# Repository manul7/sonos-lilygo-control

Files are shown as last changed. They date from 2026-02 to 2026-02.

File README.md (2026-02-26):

# TTGO Sonos Volume Controller

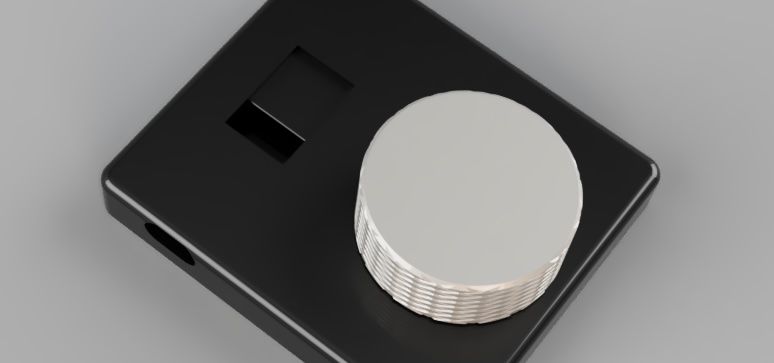
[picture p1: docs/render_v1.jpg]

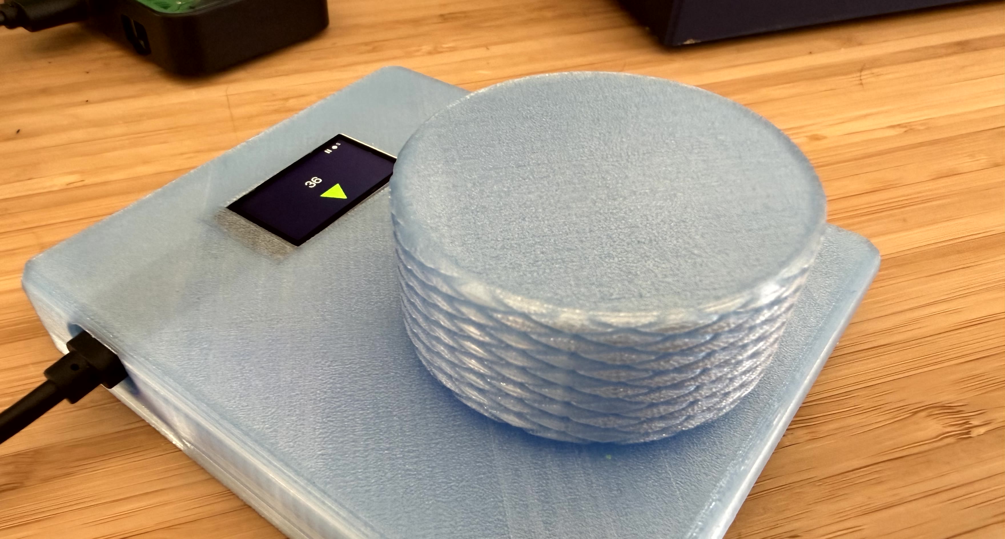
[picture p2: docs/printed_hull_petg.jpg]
Hull


ESP32-based hardware volume knob for Sonos speakers using a TTGO T-Display board.

## Features

- Volume displayed as a fill-proportional triangle with numeric readout
- Status icons (WiFi, Sonos connectivity, play/pause state) in top-right corner
- Rotary encoder for smooth volume adjustment with batching
- Encoder button toggles play/pause
- Built-in buttons as fallback (up/down with auto-repeat)
- WiFi connectivity to Sonos via UPnP/SOAP
- Auto-reconnect on WiFi drop

## Hardware

- **Board**: TTGO T-Display (ESP32 with 1.14" TFT, 240x135)
- **Rotary encoder**: CLK → GPIO25, DT → GPIO26, SW → GPIO27
- **Built-in buttons**: GPIO35 (A), GPIO0 (B)

## Project Structure

```
ttgo_counter/
├── ttgo_counter.ino   # Main sketch (UI, buttons, WiFi)
├── config.h           # Configuration (excluded from git)
├── config.h.example   # Configuration template
├── sonos.h            # Sonos API declarations
├── sonos.cpp          # Sonos UPnP/SOAP implementation
├── bom.md             # Bill of materials
├── hull/              # 3D-printable enclosure (STL files)
│   ├── TopHull_v1.stl
│   ├── BottomHull_v0.stl
│   └── knob_v0.stl
└── README.md
```

## Dependencies

Install via Arduino Library Manager:

| Library | Purpose |
|---|---|
| TFT_eSPI | Display driver |
| WiFi | ESP32 WiFi (built-in) |
| HTTPClient | HTTP requests (built-in) |

### TFT_eSPI Configuration

In `User_Setup_Select.h`, enable:
```cpp
#include <User_Setups/Setup25_TTGO_T_Display.h>
```

## Configuration

Copy `config.h.example` to `config.h` and edit:

```cpp
// WiFi
static const char* WIFI_SSID = "YourNetwork";
static const char* WIFI_PASSWORD = "YourPassword";

// Sonos
static const char* SONOS_IP = "192.168.x.x";  // Your Sonos speaker IP
static const int SONOS_PORT = 1400;
static const int VOLUME_STEP = 1;

// Hardware
static const int BUTTON_A_PIN = 35;
static const int BUTTON_B_PIN = 0;
static const int ENCODER_CLK_PIN = 25;
static const int ENCODER_DT_PIN = 26;
static const int ENCODER_SW_PIN = 27;

// Display
static const uint8_t DISPLAY_ROTATION = 1;
static const bool DISPLAY_INVERT = true;

// UI Colors (RGB565)
static const uint16_t COLOR_TRI_FILL  = 0x07E0;  // bright green
static const uint16_t COLOR_ICON_ON   = 0xFFFF;  // white
static const uint16_t COLOR_ICON_OFF  = 0x4208;  // dark gray

// Triangle geometry
static const int TRI_HEIGHT   = 100;
static const int TRI_BASE     = 116;
static const int TRI_OFFSET_Y = 5;

// Status icon layout (top-right)
static const int ICON_SIZE   = 10;
static const int ICON_GAP    = 4;
static const int ICON_MARGIN = 6;

// Timing
static const uint32_t DEBOUNCE_MS = 35;
static const uint32_t LONG_PRESS_MS = 700;
static const uint32_t REPEAT_INTERVAL_MS = 300;
```

Note: `config.h` contains credentials and is excluded from version control.

## Usage

- **Encoder rotation**: Volume up/down
- **Encoder button**: Play/pause toggle
- **Button A (GPIO35)**: Volume up (fallback)
- **Button B (GPIO0)**: Volume down (fallback)
- Hold built-in buttons for auto-repeat

Single-button mode activates automatically if only one built-in button is detected.

## Display

The screen shows a triangle that fills proportionally to the current volume (0-100), with the numeric value overlaid. Status icons in the top-right corner indicate:

- **WiFi**: filled circle (green = connected, gray = disconnected)
- **Sonos**: "S" letter (green = reachable, gray = unreachable)
- **Playback**: play/pause icon reflecting current transport state

## Enclosure

3D-printable STL files are in [hull/](hull/). Print the top and bottom hull halves plus the encoder knob. See [bom.md](bom.md) for parts sourcing.

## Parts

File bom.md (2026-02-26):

# Bill of Materials

- **LilyGO TTGO T-Display** - ESP32 board with 1.14" TFT display
  [LilyGO Official Store](https://lilygo.cc/en-us/products/t-display)

- **Rotary Encoder (5-Pack)** - Taiss KY-040 rotary encoder module for Arduino, ESP32, ESP8266, Raspberry Pi
  [Amazon](https://www.amazon.com/dp/B07F26CT6B)

- **PETG** - Plastic for the hull print
- **Nylon hex M3 stud** x 4
- **Nylon M3 screw** x 4

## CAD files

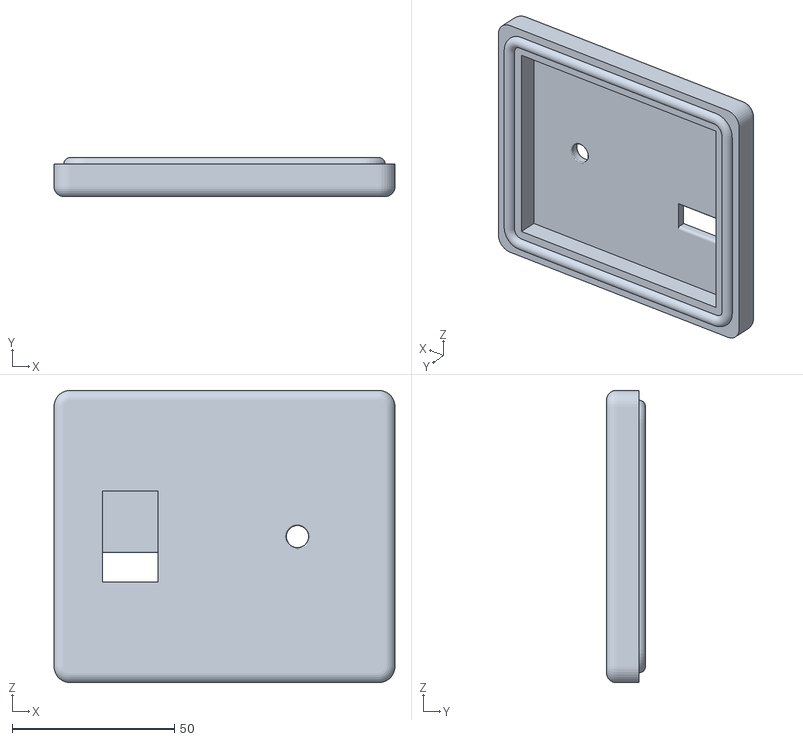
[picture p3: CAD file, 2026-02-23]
hull/TopHull_v1.stl
105.0 x 12.0 x 90.0

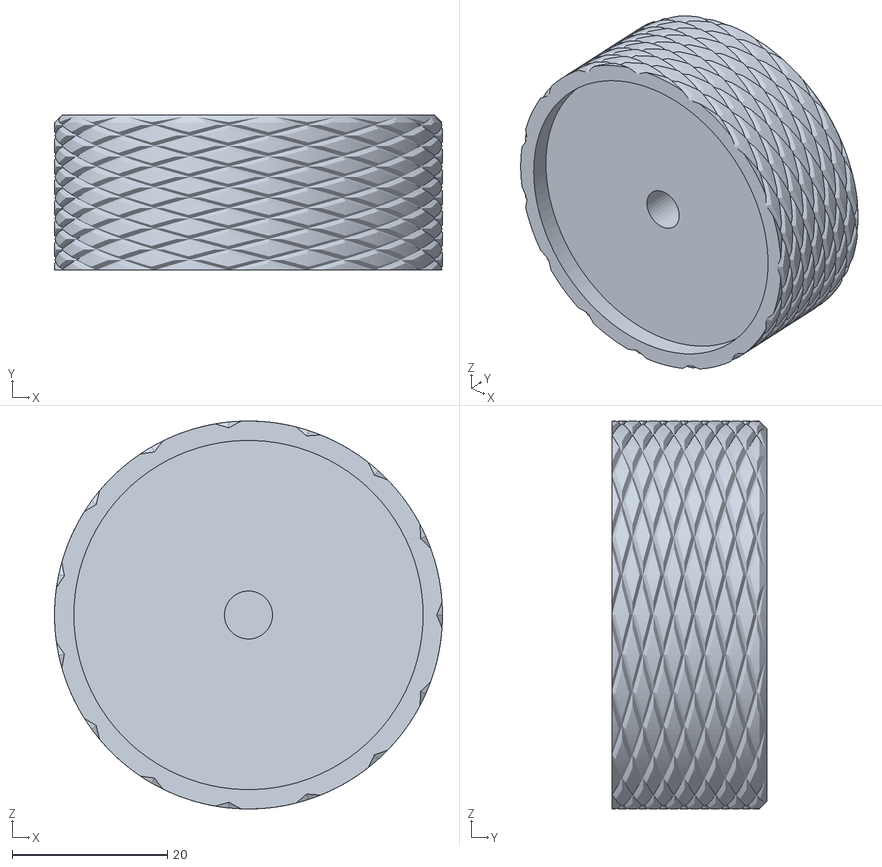
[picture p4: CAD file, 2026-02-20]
hull/knob_v0.stl
50.0 x 20.0 x 50.0

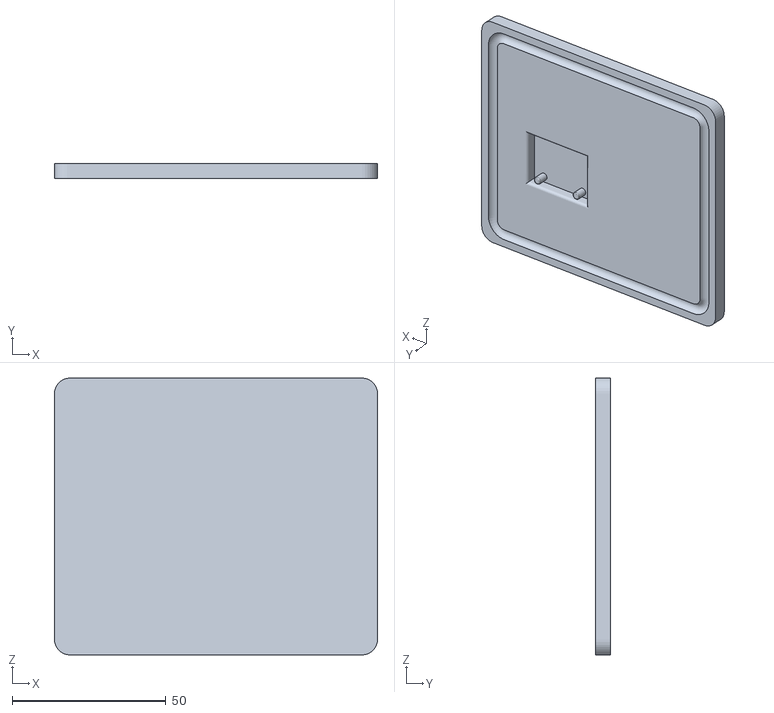
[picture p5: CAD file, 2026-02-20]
hull/BottomHull_v0.stl
105.0 x 5.00 x 90.0

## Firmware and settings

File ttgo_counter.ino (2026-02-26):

#include <TFT_eSPI.h>
#include <WiFi.h>
#include "config.h"
#include "sonos.h"

namespace {

struct Button {
  int pin;
  bool active_low;
  bool enabled;
  bool raw_pressed;
  bool stable_pressed;
  uint32_t last_raw_change_ms;
  uint32_t pressed_since_ms;
};

enum class ButtonEventType { None, Press, Release };

struct ButtonEvent {
  ButtonEventType type;
  uint32_t held_ms;
};

TFT_eSPI tft = TFT_eSPI();
Button button_a{};
Button button_b{};
Button encoder_sw{};

int current_volume = 0;
bool single_button_mode = false;
uint32_t last_repeat_a_ms = 0;
uint32_t last_repeat_b_ms = 0;

// Encoder state
volatile int encoder_pos = 0;
int last_encoder_pos = 0;
volatile int last_clk_state = HIGH;

// Volume batching
uint32_t last_encoder_change_ms = 0;
int pending_volume_delta = 0;
static const uint32_t VOLUME_BATCH_MS = 50;  // batch rapid turns

int majorityRead(int pin) {
  int highs = 0;
  for (int i = 0; i < 7; ++i) {
    highs += (digitalRead(pin) == HIGH) ? 1 : 0;
    delayMicroseconds(250);
  }
  return (highs >= 4) ? HIGH : LOW;
}

bool readPressed(const Button &button) {
  const int level = majorityRead(button.pin);
  return button.active_low ? (level == LOW) : (level == HIGH);
}

bool pinLooksStable(int pin) {
  int transitions = 0;
  int prev = majorityRead(pin);
  for (int i = 0; i < 120; ++i) {
    delay(2);
    const int now = majorityRead(pin);
    if (now != prev) {
      ++transitions;
      prev = now;
    }
  }
  return transitions <= 4;
}

Button makeButton(int pin, bool active_low) {
  Button b{};
  b.pin = pin;
  b.active_low = active_low;
  b.enabled = pinLooksStable(pin);
  b.raw_pressed = b.enabled ? readPressed(b) : false;
  b.stable_pressed = b.raw_pressed;
  b.last_raw_change_ms = millis();
  b.pressed_since_ms = 0;
  return b;
}

ButtonEvent updateButton(Button &b, uint32_t now_ms) {
  if (!b.enabled) {
    return {ButtonEventType::None, 0};
  }

  const bool raw_pressed = readPressed(b);
  if (raw_pressed != b.raw_pressed) {
    b.raw_pressed = raw_pressed;
    b.last_raw_change_ms = now_ms;
  }

  if ((now_ms - b.last_raw_change_ms) < DEBOUNCE_MS) {
    return {ButtonEventType::None, 0};
  }

  if (b.stable_pressed == b.raw_pressed) {
    return {ButtonEventType::None, 0};
  }

  b.stable_pressed = b.raw_pressed;
  if (b.stable_pressed) {
    b.pressed_since_ms = now_ms;
    return {ButtonEventType::Press, 0};
  }

  const uint32_t held = now_ms - b.pressed_since_ms;
  return {ButtonEventType::Release, held};
}

int pickFontToFit(const char *text, int max_width, int start_font, int min_font) {
  for (int font = start_font; font >= min_font; --font) {
    if (tft.textWidth(text, font) <= max_width) {
      return font;
    }
  }
  return min_font;
}

void drawScreen() {
  tft.fillScreen(TFT_BLACK);

  const int w = tft.width();   // 240
  const int h = tft.height();  // 135

  // Inverted triangle — flat edge at top, apex at bottom
  const int cx = w / 2;
  const int tri_cy = h / 2 + TRI_OFFSET_Y;
  const int top_y = tri_cy - TRI_HEIGHT / 2;
  const int bot_y = tri_cy + TRI_HEIGHT / 2;
  const int half_base = TRI_BASE / 2;

  // Fill from apex (bottom) upward proportional to volume.
  // The filled region is a smaller triangle sharing the apex.
  if (current_volume > 0) {
    const float frac = current_volume / 100.0f;
    // fill_y = line where fill stops (moves up from bot_y toward top_y)
    const int fill_y = bot_y - (int)(frac * TRI_HEIGHT);
    // Width at fill_y: triangle widens toward the top
    const int fill_half_w = (int)(half_base * frac);

    tft.fillTriangle(cx, bot_y,
                     cx - fill_half_w, fill_y,
                     cx + fill_half_w, fill_y,
                     COLOR_TRI_FILL);
  }

  // Volume number centered in upper portion of triangle
  char vol_text[8];
  snprintf(vol_text, sizeof(vol_text), "%d", current_volume);
  tft.setTextDatum(MC_DATUM);
  tft.setTextColor(TFT_WHITE);
  const int text_y = top_y + TRI_HEIGHT / 3;
  const int font = pickFontToFit(vol_text, half_base, 4, 2);
  tft.drawString(vol_text, cx, text_y, font);

  // Status icons — top-right corner
  const bool wifi_ok = (WiFi.status() == WL_CONNECTED);
  const bool sonos_ok = sonosIsConnected();
  const bool playing = sonosIsPlaying();

  // Rightmost icon x position
  int ix = w - ICON_MARGIN - ICON_SIZE;
  const int iy = ICON_MARGIN;

  // Sonos indicator: "S" letter
  tft.setTextDatum(TL_DATUM);
  tft.setTextColor(sonos_ok ? COLOR_ICON_ON : COLOR_ICON_OFF);
  tft.drawString("S", ix, iy, 1);

  ix -= (ICON_SIZE + ICON_GAP);

  // WiFi indicator: filled circle
  tft.fillCircle(ix + ICON_SIZE / 2, iy + ICON_SIZE / 2, ICON_SIZE / 2 - 1,
                 wifi_ok ? COLOR_ICON_ON : COLOR_ICON_OFF);

  ix -= (ICON_SIZE + ICON_GAP);

  // Play/pause indicator
  if (playing) {
    // Triangle (play icon)
    tft.fillTriangle(ix, iy, ix, iy + ICON_SIZE,
                     ix + ICON_SIZE, iy + ICON_SIZE / 2,
                     COLOR_ICON_ON);
  } else {
    // Two bars (pause icon)
    const int bar_w = 3;
    const int gap = 2;
    tft.fillRect(ix, iy, bar_w, ICON_SIZE, COLOR_ICON_ON);
    tft.fillRect(ix + bar_w + gap, iy, bar_w, ICON_SIZE, COLOR_ICON_ON);
  }
}

void changeVolume(int delta) {
  int new_volume = current_volume + delta;
  if (new_volume < 0) new_volume = 0;
  if (new_volume > 100) new_volume = 100;
  if (new_volume == current_volume) return;

  if (sonosSetVolume(new_volume)) {
    current_volume = new_volume;
    drawScreen();
  }
}

void showStatus(const char* msg) {
  tft.fillScreen(TFT_BLACK);
  tft.setTextColor(TFT_WHITE, TFT_BLACK);
  tft.setTextDatum(MC_DATUM);
  tft.drawString(msg, tft.width() / 2, tft.height() / 2, 4);
}

bool checkWiFi() {
  if (WiFi.status() == WL_CONNECTED) return true;

  showStatus("WiFi...");
  WiFi.reconnect();

  uint32_t start = millis();
  while (WiFi.status() != WL_CONNECTED && (millis() - start) < 10000) {
    delay(250);
  }

  if (WiFi.status() == WL_CONNECTED) {
    drawScreen();
    return true;
  }
  return false;
}

void IRAM_ATTR encoderISR() {
  const int clk = digitalRead(ENCODER_CLK_PIN);
  const int dt = digitalRead(ENCODER_DT_PIN);
  if (clk != last_clk_state && clk == LOW) {
    encoder_pos += (dt != clk) ? 1 : -1;
  }
  last_clk_state = clk;
}

}  // namespace

void setup() {
  Serial.begin(115200);
  delay(120);

  pinMode(TFT_BL, OUTPUT);
  digitalWrite(TFT_BL, HIGH);

  // GPIO35 is input-only; GPIO0 usually has external pull-up.
  pinMode(BUTTON_A_PIN, INPUT);
  pinMode(BUTTON_B_PIN, INPUT_PULLUP);

  // Rotary encoder
  pinMode(ENCODER_CLK_PIN, INPUT_PULLUP);
  pinMode(ENCODER_DT_PIN, INPUT_PULLUP);
  pinMode(ENCODER_SW_PIN, INPUT_PULLUP);
  last_clk_state = digitalRead(ENCODER_CLK_PIN);
  attachInterrupt(digitalPinToInterrupt(ENCODER_CLK_PIN), encoderISR, CHANGE);
  delay(20);

  button_a = makeButton(BUTTON_A_PIN, true);
  button_b = makeButton(BUTTON_B_PIN, true);
  encoder_sw = makeButton(ENCODER_SW_PIN, true);

  // Some board variants expose only one usable GPIO button.
  single_button_mode = (button_a.enabled && !button_b.enabled);

  Serial.printf("button_a_enabled=%d button_b_enabled=%d single_mode=%d\n",
                button_a.enabled ? 1 : 0,
                button_b.enabled ? 1 : 0,
                single_button_mode ? 1 : 0);

  tft.init();
  tft.setRotation(DISPLAY_ROTATION);
  tft.invertDisplay(DISPLAY_INVERT);

  // Show connecting message
  tft.fillScreen(TFT_BLACK);
  tft.setTextColor(TFT_WHITE, TFT_BLACK);
  tft.setTextDatum(MC_DATUM);
  tft.drawString("WiFi...", tft.width() / 2, tft.height() / 2, 4);

  // Connect to WiFi
  WiFi.begin(WIFI_SSID, WIFI_PASSWORD);
  while (WiFi.status() != WL_CONNECTED) {
    delay(500);
    Serial.print(".");
  }
  Serial.printf("\nConnected! IP: %s\n", WiFi.localIP().toString().c_str());

  // Get initial volume from Sonos
  tft.drawString("Sonos...", tft.width() / 2, tft.height() / 2, 4);
  current_volume = sonosGetVolume();
  if (current_volume < 0) current_volume = 0;

  drawScreen();
}

void loop() {
  const uint32_t now = millis();

  // Handle rotary encoder rotation with batching
  noInterrupts();
  const int pos = encoder_pos;
  interrupts();

  if (pos != last_encoder_pos) {
    pending_volume_delta += (pos - last_encoder_pos) * VOLUME_STEP;
    last_encoder_pos = pos;
    last_encoder_change_ms = now;
  }

  // Apply batched volume change after settling
  if (pending_volume_delta != 0 && (now - last_encoder_change_ms) >= VOLUME_BATCH_MS) {
    if (checkWiFi()) {
      changeVolume(pending_volume_delta);
    }
    pending_volume_delta = 0;
  }

  // Handle encoder SW button for play/pause
  const ButtonEvent sw_event = updateButton(encoder_sw, now);
  if (sw_event.type == ButtonEventType::Press) {
    if (checkWiFi()) {
      sonosTogglePlayPause();
      drawScreen();
    }
  }

  // Keep built-in buttons as fallback
  const ButtonEvent a_event = updateButton(button_a, now);
  const ButtonEvent b_event = updateButton(button_b, now);

  if (single_button_mode) {
    if (a_event.type == ButtonEventType::Release) {
      changeVolume((a_event.held_ms >= LONG_PRESS_MS) ? -VOLUME_STEP : +VOLUME_STEP);
    }
  } else {
    if (a_event.type == ButtonEventType::Press) {
      changeVolume(+VOLUME_STEP);
      last_repeat_a_ms = now;
    }
    if (b_event.type == ButtonEventType::Press) {
      changeVolume(-VOLUME_STEP);
      last_repeat_b_ms = now;
    }
    if (button_a.stable_pressed && (now - last_repeat_a_ms) >= REPEAT_INTERVAL_MS) {
      changeVolume(+VOLUME_STEP);
      last_repeat_a_ms = now;
    }
    if (button_b.stable_pressed && (now - last_repeat_b_ms) >= REPEAT_INTERVAL_MS) {
      changeVolume(-VOLUME_STEP);
      last_repeat_b_ms = now;
    }
  }

  delay(4);
}

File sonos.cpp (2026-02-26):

#include "sonos.h"

namespace {

bool s_connected = false;
bool s_playing = false;

String sonosRenderingUrl() {
  return String("http://") + SONOS_IP + ":" + SONOS_PORT + "/MediaRenderer/RenderingControl/Control";
}

String sonosTransportUrl() {
  return String("http://") + SONOS_IP + ":" + SONOS_PORT + "/MediaRenderer/AVTransport/Control";
}

}  // namespace

static const int HTTP_TIMEOUT_MS = 2000;

bool sonosIsConnected() { return s_connected; }
bool sonosIsPlaying()   { return s_playing; }

int sonosGetVolume() {
  HTTPClient http;
  http.begin(sonosRenderingUrl());
  http.setTimeout(HTTP_TIMEOUT_MS);
  http.addHeader("Content-Type", "text/xml; charset=\"utf-8\"");
  http.addHeader("SOAPACTION", "\"urn:schemas-upnp-org:service:RenderingControl:1#GetVolume\"");

  const char* body =
    "<?xml version=\"1.0\"?>"
    "<s:Envelope xmlns:s=\"http://schemas.xmlsoap.org/soap/envelope/\" "
    "s:encodingStyle=\"http://schemas.xmlsoap.org/soap/encoding/\">"
    "<s:Body>"
    "<u:GetVolume xmlns:u=\"urn:schemas-upnp-org:service:RenderingControl:1\">"
    "<InstanceID>0</InstanceID>"
    "<Channel>Master</Channel>"
    "</u:GetVolume>"
    "</s:Body>"
    "</s:Envelope>";

  int httpCode = http.POST(body);
  int volume = -1;
  s_connected = (httpCode == 200);

  if (httpCode == 200) {
    String response = http.getString();
    int start = response.indexOf("<CurrentVolume>");
    int end = response.indexOf("</CurrentVolume>");
    if (start > 0 && end > start) {
      volume = response.substring(start + 15, end).toInt();
    } else {
      Serial.println("GetVolume: missing <CurrentVolume> in response");
    }
  } else {
    Serial.printf("GetVolume failed: HTTP %d\n", httpCode);
  }
  http.end();
  return volume;
}

bool sonosSetVolume(int volume) {
  if (volume < 0) volume = 0;
  if (volume > 100) volume = 100;

  HTTPClient http;
  http.begin(sonosRenderingUrl());
  http.setTimeout(HTTP_TIMEOUT_MS);
  http.addHeader("Content-Type", "text/xml; charset=\"utf-8\"");
  http.addHeader("SOAPACTION", "\"urn:schemas-upnp-org:service:RenderingControl:1#SetVolume\"");

  String body = String(
    "<?xml version=\"1.0\"?>"
    "<s:Envelope xmlns:s=\"http://schemas.xmlsoap.org/soap/envelope/\" "
    "s:encodingStyle=\"http://schemas.xmlsoap.org/soap/encoding/\">"
    "<s:Body>"
    "<u:SetVolume xmlns:u=\"urn:schemas-upnp-org:service:RenderingControl:1\">"
    "<InstanceID>0</InstanceID>"
    "<Channel>Master</Channel>"
    "<DesiredVolume>") + volume + String("</DesiredVolume>"
    "</u:SetVolume>"
    "</s:Body>"
    "</s:Envelope>");

  int httpCode = http.POST(body);
  s_connected = (httpCode == 200);
  if (httpCode != 200) {
    Serial.printf("SetVolume(%d) failed: HTTP %d\n", volume, httpCode);
  }
  http.end();
  return httpCode == 200;
}

bool sonosTogglePlayPause() {
  HTTPClient http;
  http.begin(sonosTransportUrl());
  http.setTimeout(HTTP_TIMEOUT_MS);
  http.addHeader("Content-Type", "text/xml; charset=\"utf-8\"");
  http.addHeader("SOAPACTION", "\"urn:schemas-upnp-org:service:AVTransport:1#GetTransportInfo\"");

  const char* getStateBody =
    "<?xml version=\"1.0\"?>"
    "<s:Envelope xmlns:s=\"http://schemas.xmlsoap.org/soap/envelope/\" "
    "s:encodingStyle=\"http://schemas.xmlsoap.org/soap/encoding/\">"
    "<s:Body>"
    "<u:GetTransportInfo xmlns:u=\"urn:schemas-upnp-org:service:AVTransport:1\">"
    "<InstanceID>0</InstanceID>"
    "</u:GetTransportInfo>"
    "</s:Body>"
    "</s:Envelope>";

  int httpCode = http.POST(getStateBody);
  bool isPlaying = false;
  s_connected = (httpCode == 200);

  if (httpCode == 200) {
    String response = http.getString();
    isPlaying = response.indexOf("PLAYING") > 0;
  } else {
    Serial.printf("GetTransportInfo failed: HTTP %d\n", httpCode);
  }
  http.end();

  http.begin(sonosTransportUrl());
  http.setTimeout(HTTP_TIMEOUT_MS);
  http.addHeader("Content-Type", "text/xml; charset=\"utf-8\"");

  if (isPlaying) {
    http.addHeader("SOAPACTION", "\"urn:schemas-upnp-org:service:AVTransport:1#Pause\"");
    const char* pauseBody =
      "<?xml version=\"1.0\"?>"
      "<s:Envelope xmlns:s=\"http://schemas.xmlsoap.org/soap/envelope/\" "
      "s:encodingStyle=\"http://schemas.xmlsoap.org/soap/encoding/\">"
      "<s:Body>"
      "<u:Pause xmlns:u=\"urn:schemas-upnp-org:service:AVTransport:1\">"
      "<InstanceID>0</InstanceID>"
      "</u:Pause>"
      "</s:Body>"
      "</s:Envelope>";
    httpCode = http.POST(pauseBody);
  } else {
    http.addHeader("SOAPACTION", "\"urn:schemas-upnp-org:service:AVTransport:1#Play\"");
    const char* playBody =
      "<?xml version=\"1.0\"?>"
      "<s:Envelope xmlns:s=\"http://schemas.xmlsoap.org/soap/envelope/\" "
      "s:encodingStyle=\"http://schemas.xmlsoap.org/soap/encoding/\">"
      "<s:Body>"
      "<u:Play xmlns:u=\"urn:schemas-upnp-org:service:AVTransport:1\">"
      "<InstanceID>0</InstanceID>"
      "<Speed>1</Speed>"
      "</u:Play>"
      "</s:Body>"
      "</s:Envelope>";
    httpCode = http.POST(playBody);
  }

  s_connected = (httpCode == 200);
  if (httpCode == 200) {
    s_playing = !isPlaying;  // toggled: was playing → now paused, vice versa
  }
  if (httpCode != 200) {
    Serial.printf("%s failed: HTTP %d\n", isPlaying ? "Pause" : "Play", httpCode);
  }
  http.end();
  return httpCode == 200;
}

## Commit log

2026-02-18 feat: initial commit with minimal functionality
    the app can:
    - connect to specified Wi-Fi network using credentials in config.h
    - connect to remove Sonos speaker
    - increase/decrease speaker's volume
    - show current volume on the display
2026-02-20 feat: add rotaty envoded with play/pause
    - Add rotary encoder support for volume control (GPIO25/26)
    - Add encoder button support (GPIO27) for play/pause
    - Add HTTP timeout for hangs prevention
    - Add Wi-Fi re-connect with status
    - Add volume batch to prevent HTTP flood on fast turns
    - Make last_clk_state volatile for ISR safety
    [sonos.cpp, ttgo_counter.ino]
2026-02-20 docs: update readme and example condif
    - Update README with encoder features and wiring
    - Add encoder pins to config.h.example
    - Update usage section with encoder controls
2026-02-20 docs: added hull render and bom
2026-02-20 hull: add draft version of hull and knob
    [BottomHull_v0.stl, knob_v0.stl, tophull_v0.stl]
2026-02-23 hull: update top hull
    - move encoder hole to the center position
    - add hole for screen
    [TopHull_v1.stl, tophull_v0.stl]
2026-02-26 fix: logging & orientation
    - rotated text by 180 grad to fit case
    - added explicit error logging
    [sonos.cpp]
2026-02-26 feat: visual indicators
    Replace plain volume number with inverted triangle fill indicator
    proportional to volume level, plus top-right status icons for
    play/pause, WiFi connectivity, and Sonos reachability.
    [sonos.cpp, ttgo_counter.ino]
